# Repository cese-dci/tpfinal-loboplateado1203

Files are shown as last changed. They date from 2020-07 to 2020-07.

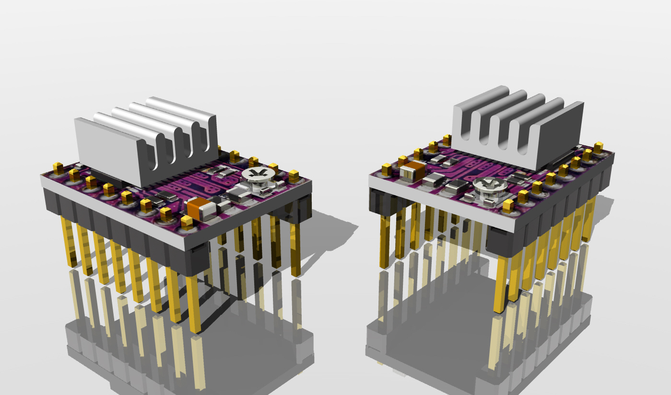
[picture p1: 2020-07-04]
Componentes/drv8825-1.snapshot.5/Renderings/8825-4.jpg

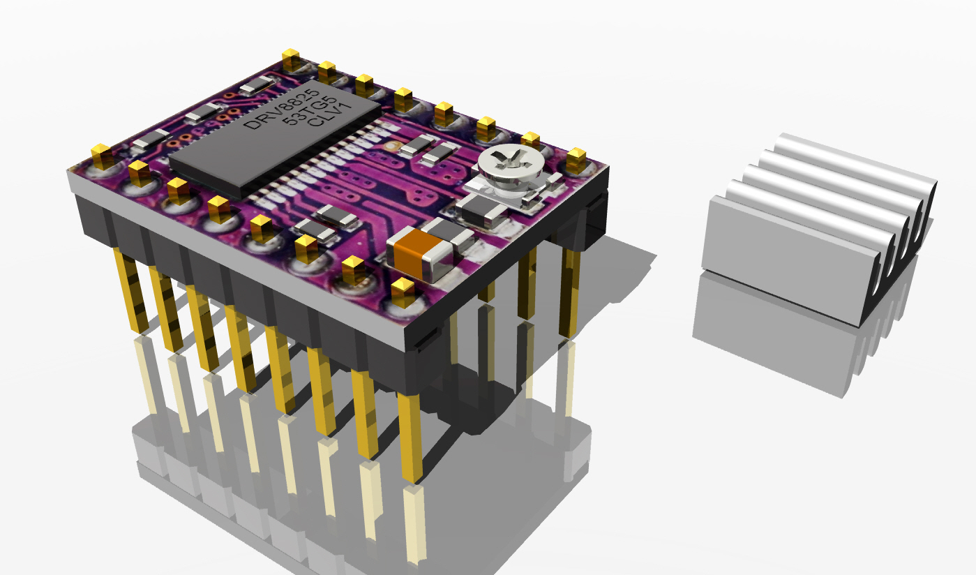
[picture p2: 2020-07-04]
Componentes/drv8825-1.snapshot.5/DRV8825.jpg

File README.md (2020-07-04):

# tpfinal-loboplateado1203
tpfinal-loboplateado1203 created by GitHub Classroom
TP Final : Diseño de Circuitos Impresos 

Poncho Drivers EDU-CIAA. 

Pensado para  el manejo de motores PAP, con el fin de diseñar un prototipo, de un máquina  destinada para doblar alambre 
/ caños.
Se diseñar una placa, para implementar la utilización de tres drivers,destinada al manejo de motores paso a paso y a su vez, 
se deja dispuesto un conector par la utilización de un teclado, para comunicarse con la dobladora de alambre. Por  dicho 
teclado se ingresan los grados y el sentido, en que debe girar el motor para realizar el diseño esperado.
El poncho realizado para esta materia forma parte del trabajo final de la especialización  - CESE 8va cohorte.

Autor
Lic. Zacharewicz L.B.

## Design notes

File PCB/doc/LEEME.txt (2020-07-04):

TITULO PONCHO: Poncho Drivers
=============

<<Colocar información mínima y propósito del Poncho.>>

Diseñar una placa para implementar la utilización de tres drivers para el manejo de motores
paso a paso y un teclado para comunicarse con la dobladora de alambre ingresar por
teclado los grados y la dirección en que debe girar el motor para realizar el diseño
esperado.

URL: https://github.com/cese-dci/tpfinal-loboplateado1203

FUNCIÓN: El Poncho sirve para el manejo de motores PAP.

AUTORES/INSTITUCIONES: Zacharewicz L.B.

<<Detalle y explicación de directorios o archivos adicionales que se incorporen.>>
Se encuentra en el PDF adjunto: Diseño de Poncho Driver

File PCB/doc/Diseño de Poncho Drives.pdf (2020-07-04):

Diseño de Circuito Impresos Especialización de Sistemas Embebidos

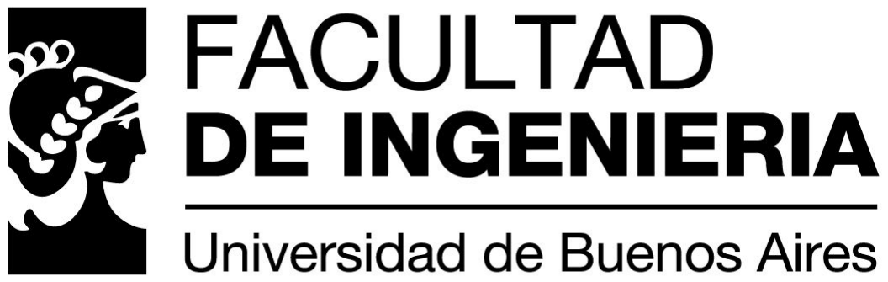
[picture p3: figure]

Diseño de Poncho -Drivers.

### Para la interacción con una dobladora de alambre

Objetivo

Diseñar una placa para implementar la utilización de tres drivers para el manejo de motores paso a paso y un teclado para comunicarse con la dobladora de alambre ingresar por teclado los grados y la dirección en que debe girar el motor para realizar el diseño esperado.

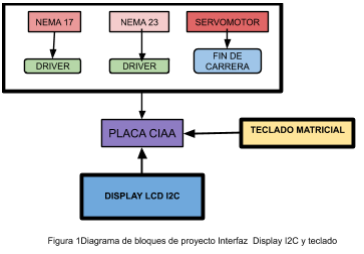
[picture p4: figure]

En la Figura 1 se muestra el diagrama de bloques de la máquina dobladora de alambre con las interfaces que utiliza. Se implementa una comunicación paralela para el teclado matricial (y un i2c que no entra en el diseño de la placa).
Mediante el teclado se ingresaran acciones a realizar por la dobladora de alambre. El teclado contará con 16 opciones de distintas tareas a realizar .
En una primera instancia se pretende la utilización de esta interfaz conectada a la EDU-CIAA y finalmente será implementada en el proyecto final con el microcontrolador 16F819 I2C esclavo, como se puede apreciar en la Figura 2

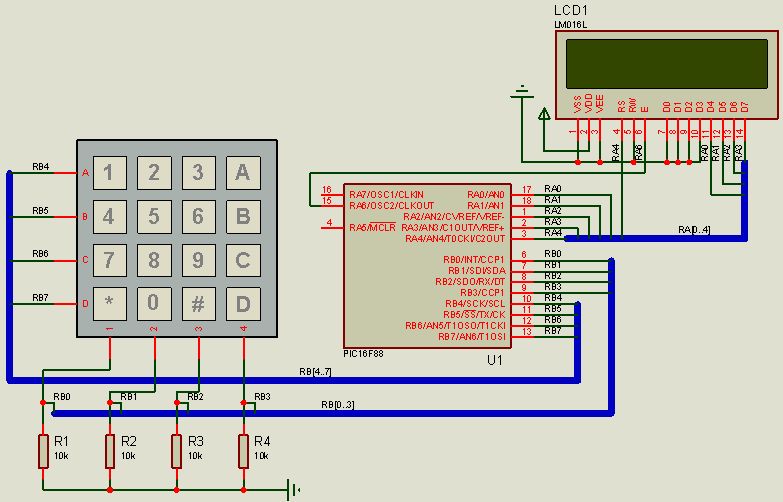
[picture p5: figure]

Figura 2

Lic. Zacharewicz L.B. | 2020

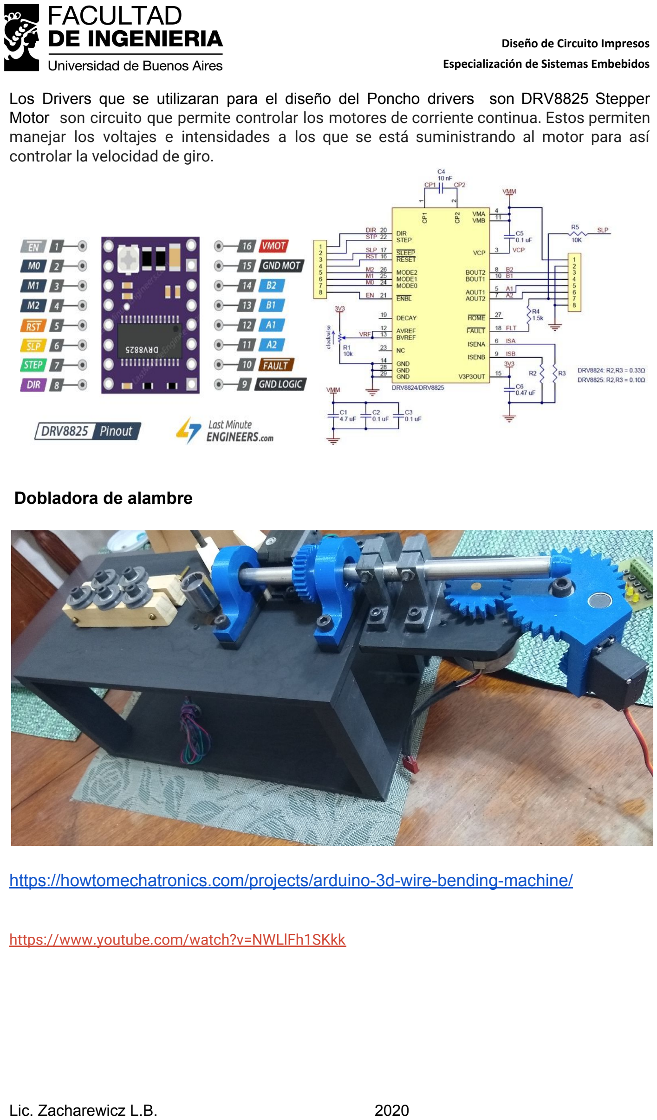
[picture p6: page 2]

Diseño de Circuito Impresos Especialización de Sistemas Embebidos

Los Drivers que se utilizaran para el diseño del Poncho drivers son DRV8825 Stepper Motor son circuito que permite controlar los motores de corriente continua. Estos permiten manejar los voltajes e intensidades a los que se está suministrando al motor para así controlar la velocidad de giro.

Dobladora de alambre

https://howtomechatronics.com/projects/arduino-3d-wire-bending-machine/

https://www.youtube.com/watch?v=NWLlFh1SKkk

Lic. Zacharewicz L.B. | 2020

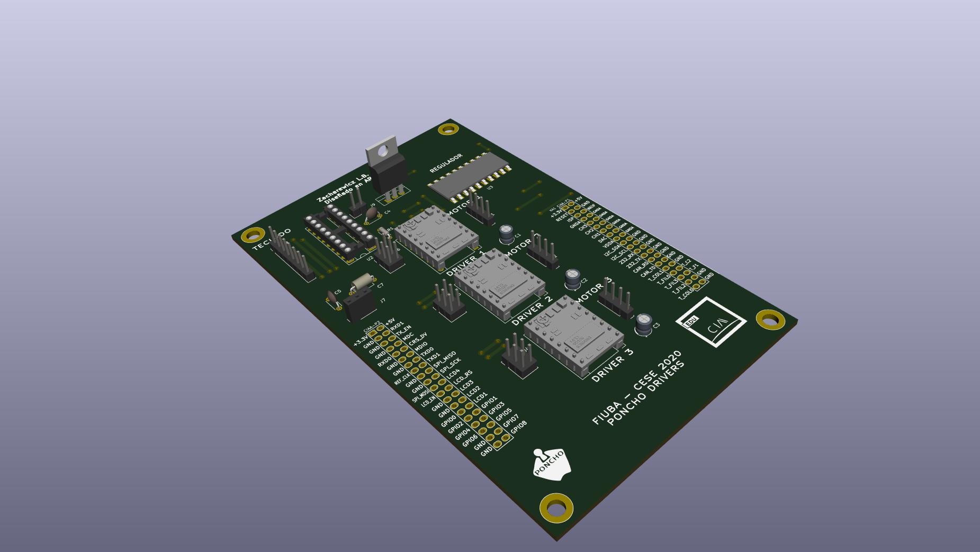
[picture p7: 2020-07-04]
PCB/tpfinal_Driver.jpg

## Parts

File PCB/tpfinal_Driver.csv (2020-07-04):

Id | Identificador | Empaquetado | Cantidad | Identificación | Suministrador y ref
1 | G*** | Logo_Poncho | 1 | LOGO
2 | G*** | Logo_EDU-CIAA | 1 | Logo_EDU-CIAA
3 | XA1 | Conn_Poncho_Completo | 1 | Conn_Poncho2P_2x_20x2
4 | A1,A2,A3 | Pololu_Breakout-16_15.2x20.3mm | 3 | Pololu_DRV8825
5 | C1,C2,C3 | CP_Radial_D4.0mm_P2.00mm | 3 | 100 uf
6 | C4,C5 | C_Disc_D4.3mm_W1.9mm_P5.00mm | 2 | 0.47 uf
7 | C7 | C_Axial_L5.1mm_D3.1mm_P7.50mm_Horizontal | 1 | 10uf
8 | J1 | PinHeader_1x04_P2.54mm_Vertical | 1 | Motor 1
9 | J2 | PinHeader_1x04_P2.54mm_Vertical | 1 | Motor 2
10 | J3 | PinHeader_1x04_P2.54mm_Vertical | 1 | Motor 3
11 | J4,J5,J6 | PinHeader_2x03_P2.54mm_Vertical | 3 | Conn_02x03
12 | J7 | PinSocket_1x03_P2.54mm_Vertical | 1 | Conn_01x03
13 | J8 | PinHeader_1x08_P2.54mm_Vertical | 1 | Conn_01x08
14 | J9 | PinHeader_1x02_P2.54mm_Vertical | 1 | Conn_01x02
15 | R1 | R_Axial_DIN0204_L3.6mm_D1.6mm_P5.08mm_Horizontal | 1 | 100k
16 | U2 | DIP-18_W7.62mm_Socket_LongPads | 1 | PIC16F648A-IP
17 | U3 | CJMCU TXB0108 Arduino | 1 | TXB0108DQSR
18 | U1 | TO-220-3_Vertical | 1 | LM7812_TO220

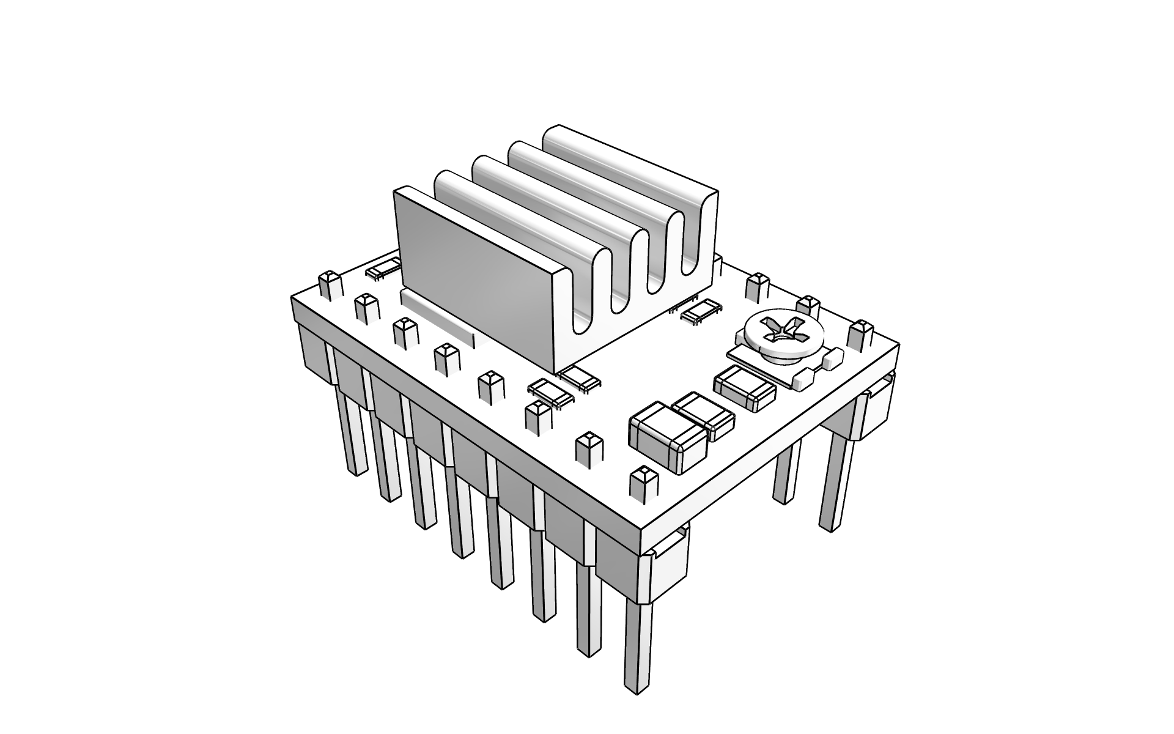
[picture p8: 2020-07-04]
Componentes/drv8825-1.snapshot.5/DRV8825.gif

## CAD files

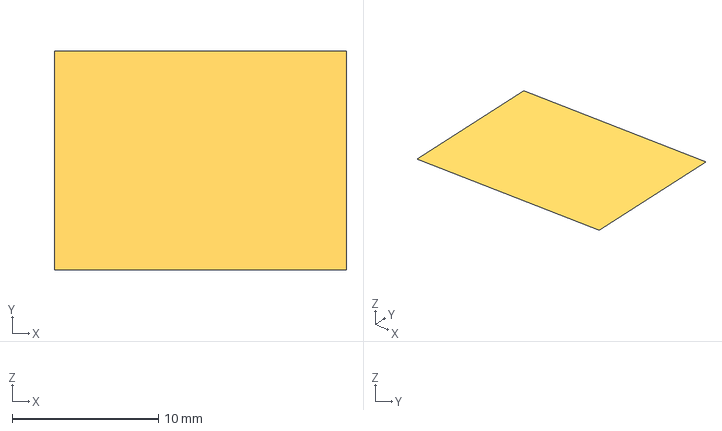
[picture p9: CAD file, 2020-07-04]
Componentes/drv8825-1.snapshot.5/8825 - Document.step
20.0 x 15.0 x 0 mm

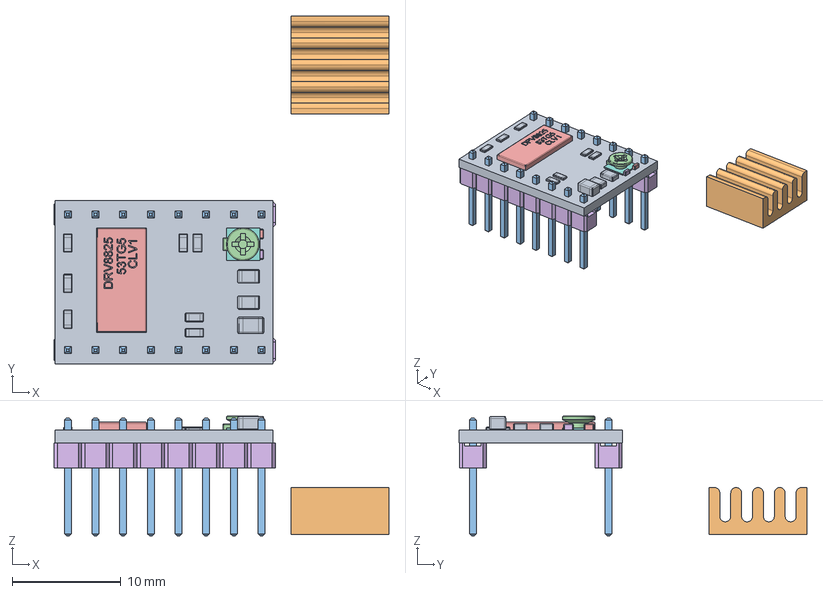
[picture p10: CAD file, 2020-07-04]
Componentes/drv8825-1.snapshot.5/8825.stp
30.8 x 31.9 x 11.0 mm

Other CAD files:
Componentes/drv8825-1.snapshot.5/8825 - Document - 1.0.stl
Componentes/drv8825-1.snapshot.5/8825 - Document.stl

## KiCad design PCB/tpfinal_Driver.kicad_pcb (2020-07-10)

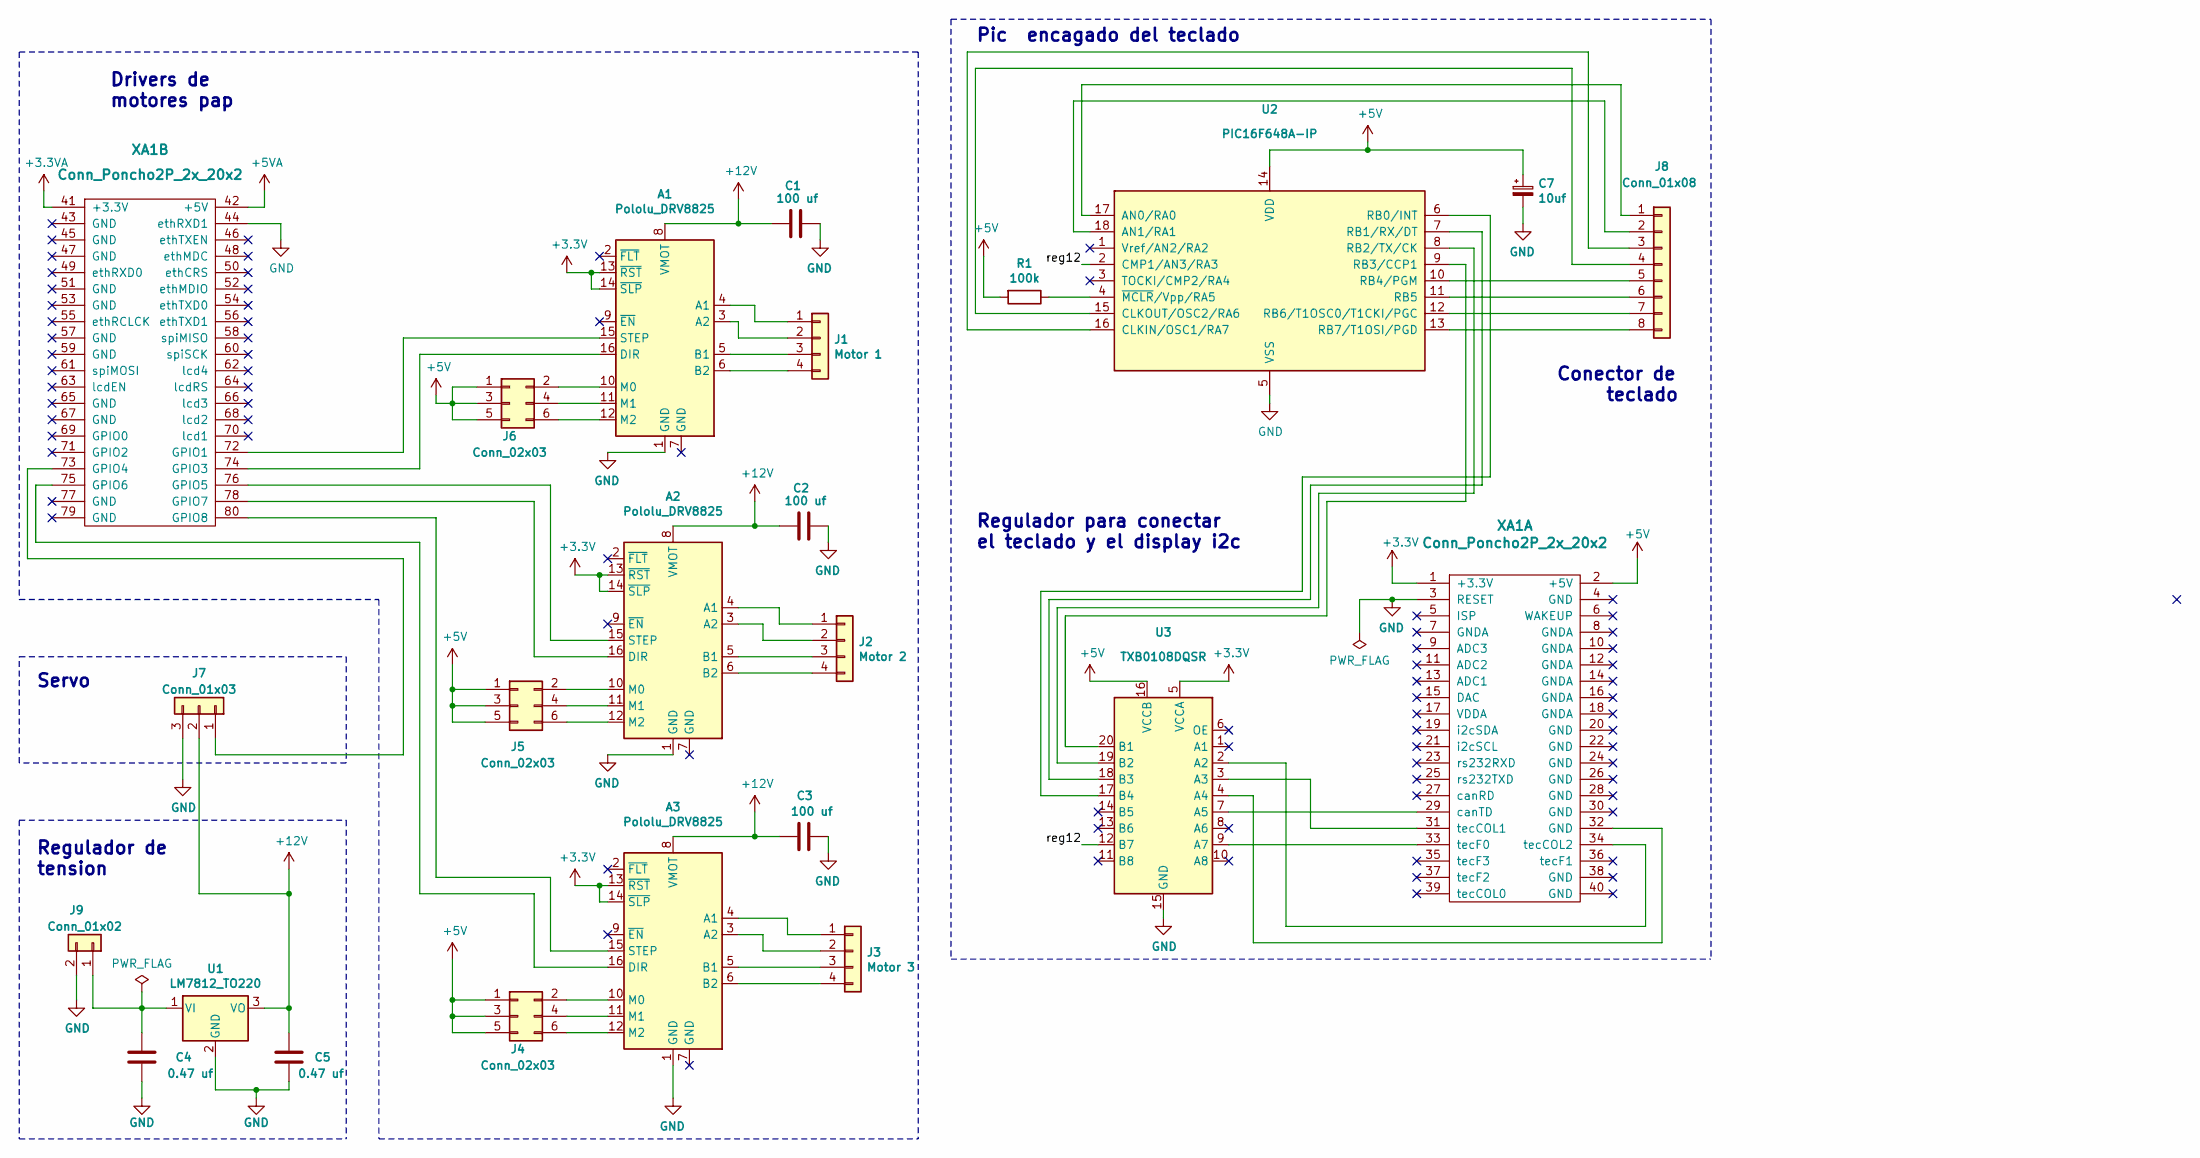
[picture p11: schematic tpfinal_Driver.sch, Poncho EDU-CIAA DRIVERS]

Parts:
A1, A2, A3: Pololu_DRV8825; Pololu_Breakout-16_15.2x20.3mm
C1, C2, C3: 100 uf; CP_Radial_D4.0mm_P2.00mm
C4, C5: 0.47 uf; C_Disc_D4.3mm_W1.9mm_P5.00mm
C7: 10uf; C_Axial_L5.1mm_D3.1mm_P7.50mm_Horizontal
J1: Motor 1; PinHeader_1x04_P2.54mm_Vertical
J2: Motor 2; PinHeader_1x04_P2.54mm_Vertical
J3: Motor 3; PinHeader_1x04_P2.54mm_Vertical
J4, J5, J6: Conn_02x03; PinHeader_2x03_P2.54mm_Vertical
J7: Conn_01x03; PinSocket_1x03_P2.54mm_Vertical
J8: Conn_01x08; PinHeader_1x08_P2.54mm_Vertical
J9: Conn_01x02; PinHeader_1x02_P2.54mm_Vertical
R1: 100k; R_Axial_DIN0204_L3.6mm_D1.6mm_P5.08mm_Horizontal
U1: LM7812_TO220; TO-220-3_Vertical
U2: PIC16F648A-IP; DIP-18_W7.62mm_Socket_LongPads
U3: TXB0108DQSR; reg_TXB0108DQSR
XA1: Conn_Poncho2P_2x_20x2; Conn_Poncho_Completo

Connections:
+3.3VA: XA1.41 (+3.3V)
+3V3: A1.13 (~RST), A1.14 (~SLP), A2.13 (~RST), A2.14 (~SLP), A3.13 (~RST), A3.14 (~SLP), U3.5 (VCCA), XA1.1 (+3.3V)
+5V: C7.1, J4.1, J4.3, J4.5, J5.1, J5.3, J5.5, J6.1, J6.3, J6.5, R1.2, U2.14 (VDD), U3.16 (VCCB), XA1.2 (+5V)
+5VA: XA1.42 (+5V)
+12V: A1.8 (VMOT), A2.8 (VMOT), A3.8 (VMOT), C1.2, C2.2, C3.2, C5.1, J7.2, U1.3 (VO)
/reg12: U2.2 (CMP1/AN3/RA3), U3.12 (B7)
GND: A1.1 (GND), A2.1 (GND), A3.1 (GND), C1.1, C2.1, C3.1, C4.2, C5.2, C7.2, J7.3, J9.2, U1.2 (GND), U2.5 (VSS), U3.15 (GND), XA1.3 (RESET), XA1.44 (ethRXD1)
unnamed: A1.3 (A2), J1.2
unnamed: A1.4 (A1), J1.1
unnamed: A1.5 (B1), J1.3
unnamed: A1.6 (B2), J1.4
unnamed: A1.10 (M0), J6.2
unnamed: A1.11 (M1), J6.4
unnamed: A1.12 (M2), J6.6
unnamed: A1.15 (STEP), XA1.72 (GPIO1)
unnamed: A1.16 (DIR), XA1.74 (GPIO3)
unnamed: A2.3 (A2), J2.2
unnamed: A2.4 (A1), J2.1
unnamed: A2.5 (B1), J2.3
unnamed: A2.6 (B2), J2.4
unnamed: A2.10 (M0), J5.2
unnamed: A2.11 (M1), J5.4
unnamed: A2.12 (M2), J5.6
unnamed: A2.15 (STEP), XA1.76 (GPIO5)
unnamed: A2.16 (DIR), XA1.78 (GPIO7)
unnamed: A3.3 (A2), J3.2
unnamed: A3.4 (A1), J3.1
unnamed: A3.5 (B1), J3.3
unnamed: A3.6 (B2), J3.4
unnamed: A3.10 (M0), J4.2
unnamed: A3.11 (M1), J4.4
unnamed: A3.12 (M2), J4.6
unnamed: A3.15 (STEP), XA1.80 (GPIO8)
unnamed: A3.16 (DIR), XA1.75 (GPIO6)
unnamed: C4.1, J9.1, U1.1 (VI)
unnamed: J7.1, XA1.73 (GPIO4)
unnamed: J8.1, U2.17 (AN0/RA0)
unnamed: J8.2, U2.18 (AN1/RA1)
unnamed: J8.3, U2.16 (CLKIN/OSC1/RA7)
unnamed: J8.4, U2.15 (CLKOUT/OSC2/RA6)
unnamed: J8.5, U2.10 (RB4/PGM)
unnamed: J8.6, U2.11 (RB5)
unnamed: J8.7, U2.12 (RB6/T1OSC0/T1CKI/PGC)
unnamed: J8.8, U2.13 (RB7/T1OSI/PGD)
unnamed: R1.1, U2.4 (~MCLR~/Vpp/RA5)
unnamed: U2.6 (RB0/INT), U3.17 (B4)
unnamed: U2.7 (RB1/RX/DT), U3.18 (B3)
unnamed: U2.8 (RB2/TX/CK), U3.19 (B2)
unnamed: U2.9 (RB3/CCP1), U3.20 (B1)
unnamed: U3.2 (A2), XA1.34 (tecCOL2)
unnamed: U3.3 (A3), XA1.31 (tecCOL1)
unnamed: U3.4 (A4), XA1.32 (GND)
unnamed: U3.7 (A5), XA1.29 (canTD)
unnamed: U3.9 (A7), XA1.33 (tecF0)

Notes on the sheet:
Regulador de tension
Servo
Regulador para conectar el teclado y el display i2c
Drivers de motores pap
Pic encagado del teclado
Conector de teclado

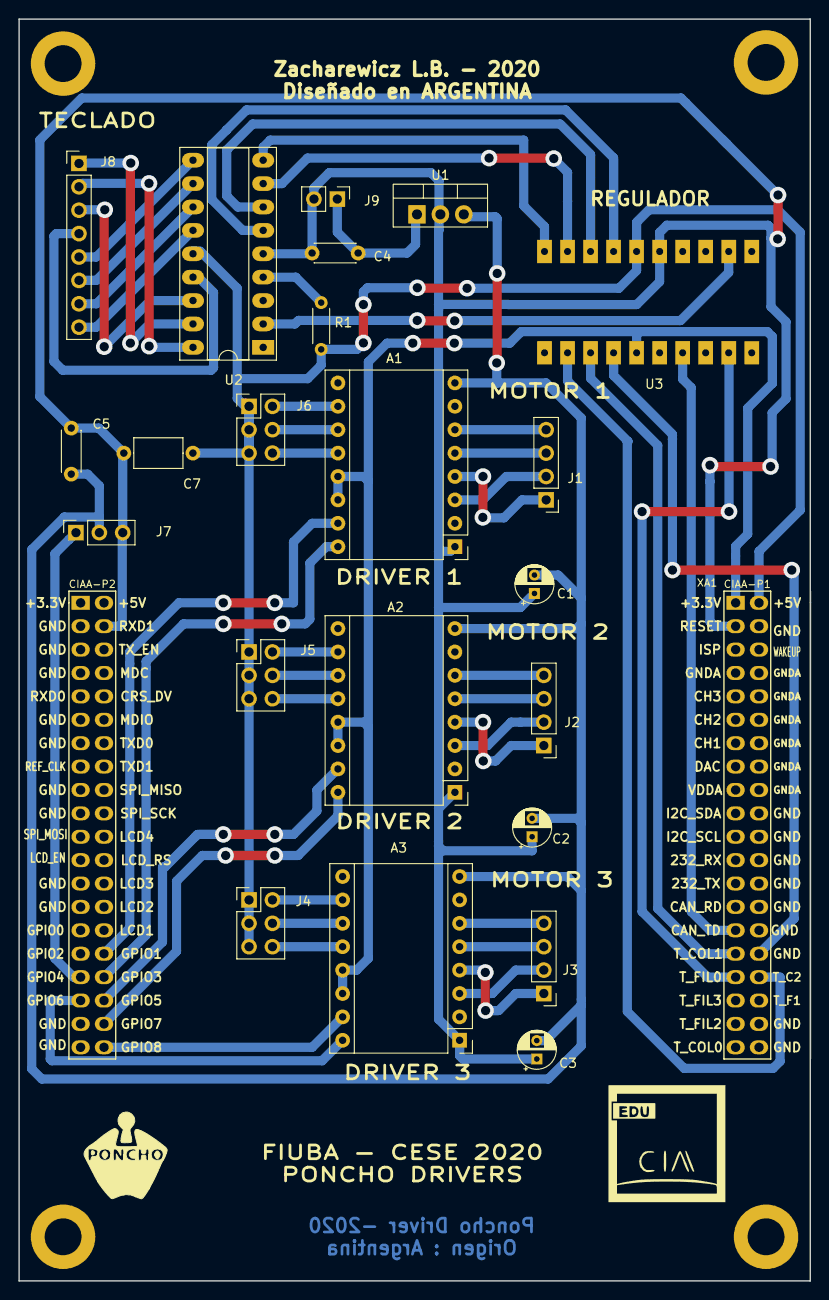
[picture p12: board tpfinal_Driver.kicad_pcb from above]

Board: 2 copper layers, 85.9 x 137.0 mm, 23 parts (0 on the bottom side), 52 nets.

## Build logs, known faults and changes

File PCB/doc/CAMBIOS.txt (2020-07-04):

Historial de cambios realizados 
================================

* Fecha: 19 de junio 2020
* Autores: Zacharewicz L.B.
* Archivos: 
* Descripción: Se parte de los Modelos de Ponchos en: 
               http://www.proyecto-ciaa.com.ar/devwiki/doku.php?id=desarrollo:edu-ciaa:ponchos_modelos
               <<Colocar aquí información de cambios importantes y de gran volumen, releases, contribuciones de terceros, etc.>>

		Porbar colocar el blouqe PIC arriba y el bloque adaptador de nivel abajo. Eso permite conectar prolijo REG20,19,18 y 17. Probar conectar también REG12 y gpio1-a4 y gpio3-a2. Si se hace prolijo queda mejor documentado el circuito. 

               "https://github.com/cese-dci/tp-dci--lmarianocampos/blob/master/Driver%20Motor%20PaP_V1.0/shapes3D/8825_sin_disip.wrl"

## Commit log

2020-07-04 Create README.md
    TP Final : Diseño de Circuitos Impresos
    Poncho Drivers EDU-CIAA.
    Pensado para el manejo de motores PAP, con el fin de diseñar un prototipo, de un maquina destinada
    para doblar alambre / caños.
    Se diseñar una placa, para implementar la utilización de tres drivers, destinada al manejo de motores
    paso a paso y a su ves, se deja dispuesto un conector par la utilizacion de un teclado, para comunicarse
    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
2020-07-04 Create README.md
    Pensado para el manejo de motores PAP, con el fin de diseñar un prototipo, de un máquina destinada para doblar alambre
    / caños.
    Se diseñar una placa, para implementar la utilización de tres drivers,destinada al manejo de motores paso a paso y a su vez,
    se deja dispuesto un conector par la utilización de un teclado, para comunicarse con la dobladora de alambre. Por dicho
    teclado se ingresan los grados y el sentido, en que debe girar el motor para realizar el diseño esperado.
    El poncho realizado para esta materia forma parte del trabajo final de la especialización - CESE 8va cohorte.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
